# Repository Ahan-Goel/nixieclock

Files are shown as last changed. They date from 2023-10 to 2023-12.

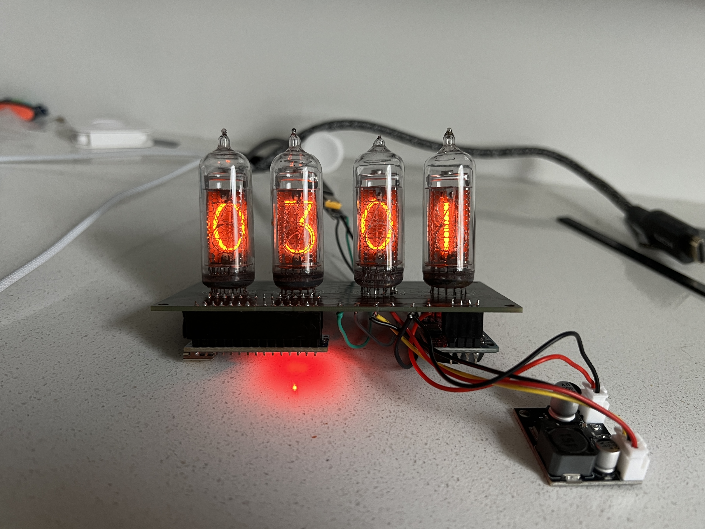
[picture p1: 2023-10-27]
Pictures/Assembled.jpeg

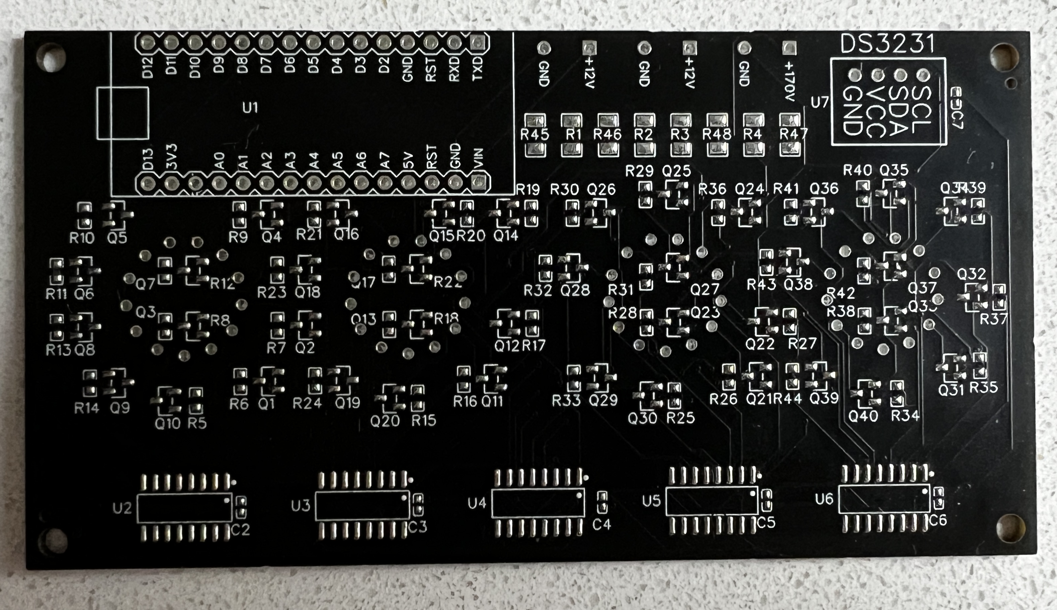
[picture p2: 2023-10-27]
Pictures/PCB Bottom.jpeg

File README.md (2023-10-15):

# nixieclock
Nixie Clock Project I worked on for my UIUC James Scholar Honors Project (ECE 220)

This project involved the research and design of a PCB that utilizes and Arduino to create a retro-themed clock using Nixie tubes.

To build this project it took a lot of research. From deciding how to control the tubes, to the firing and running voltages of the tubes, to parts selection. Using a off the shelf power supply (9v to 170v), along with 40 NPN BJT transistors, 48 resistors, and 5 SN747HC959 shift registers we can create a circuit that when controlled by a microcontroller can display digits on a nixie tube. I spent so many hours researching components, look at datasheets, understanding PCB design and schematic design, while also understanding things about Nixie tubes themselves.

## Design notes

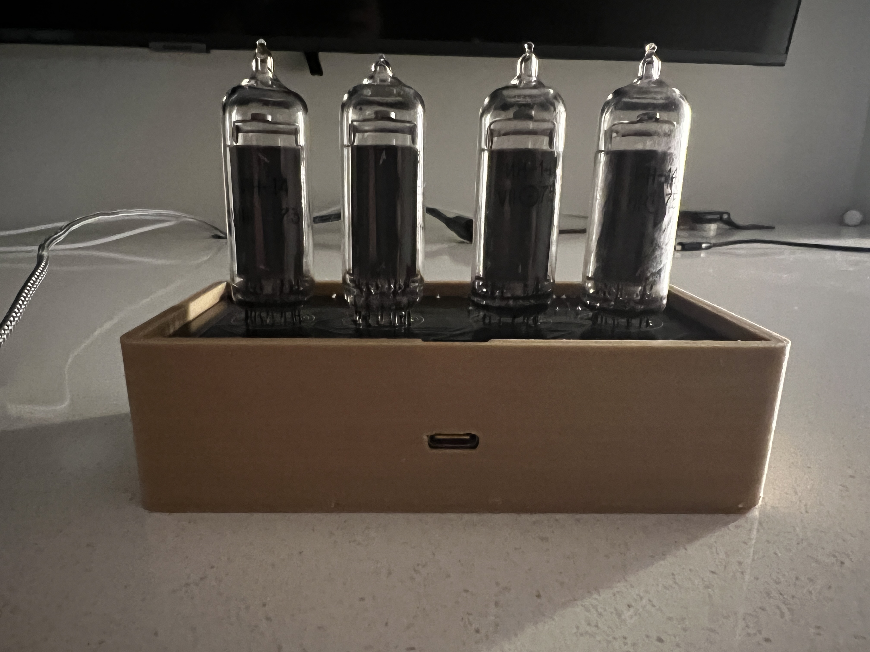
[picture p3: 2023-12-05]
Pictures/FInished Rear.JPG

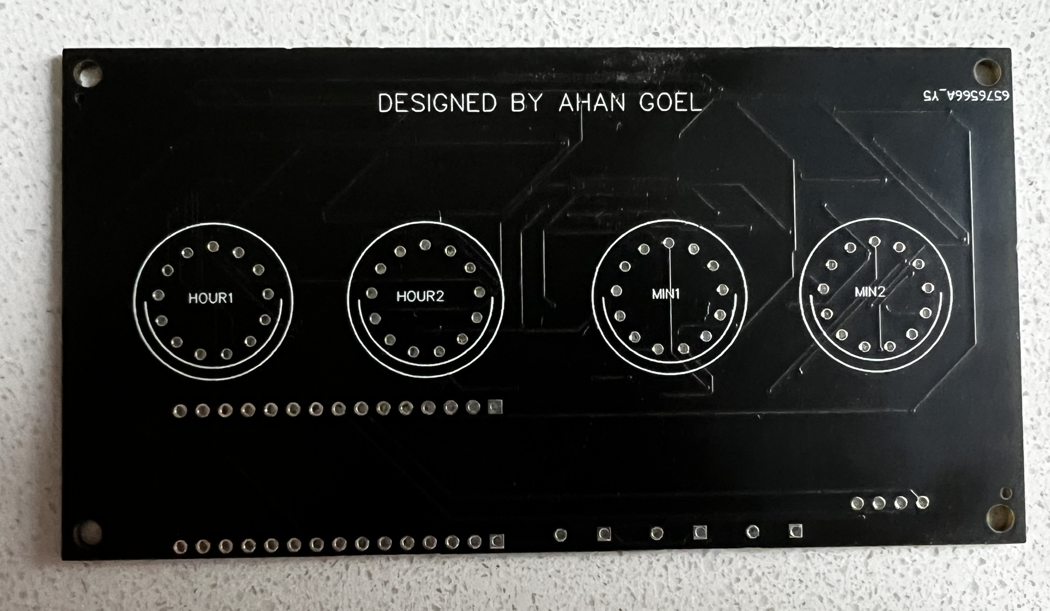
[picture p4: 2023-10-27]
Pictures/PCB Top.jpeg

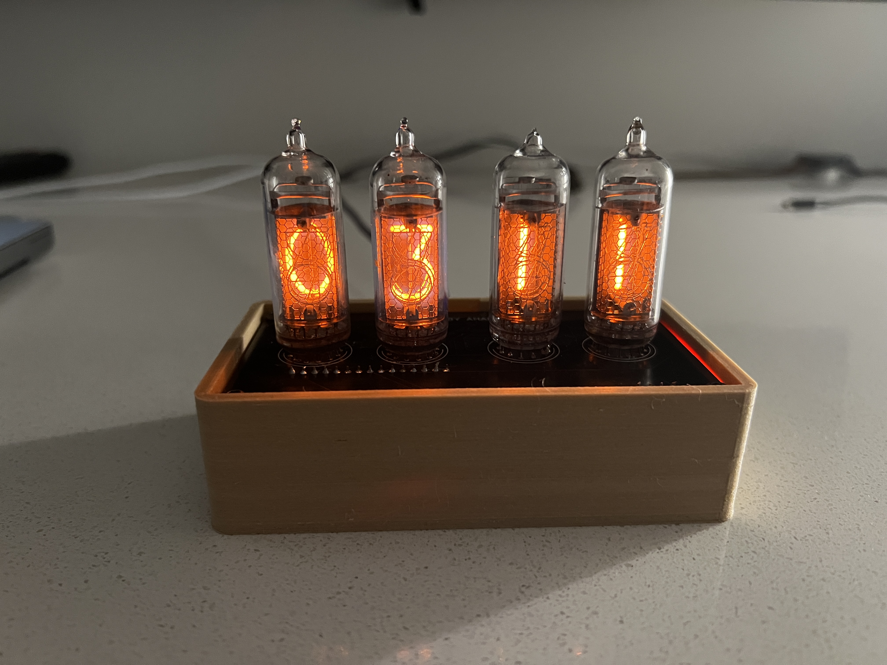
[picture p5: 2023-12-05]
Pictures/Finished Front.JPG

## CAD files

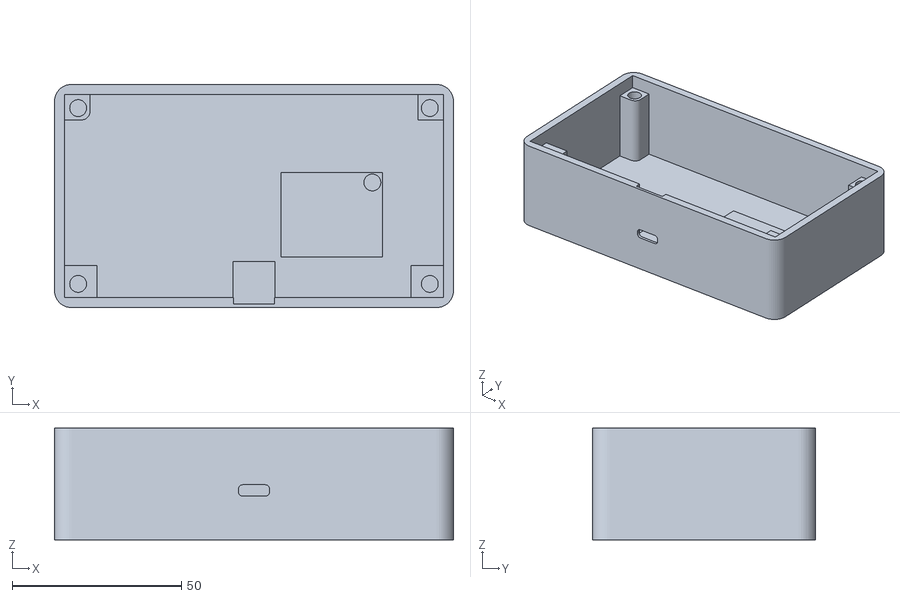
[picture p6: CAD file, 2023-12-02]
CAD Files/Nixie Clock Box.stl
118.0 x 66.0 x 33.0

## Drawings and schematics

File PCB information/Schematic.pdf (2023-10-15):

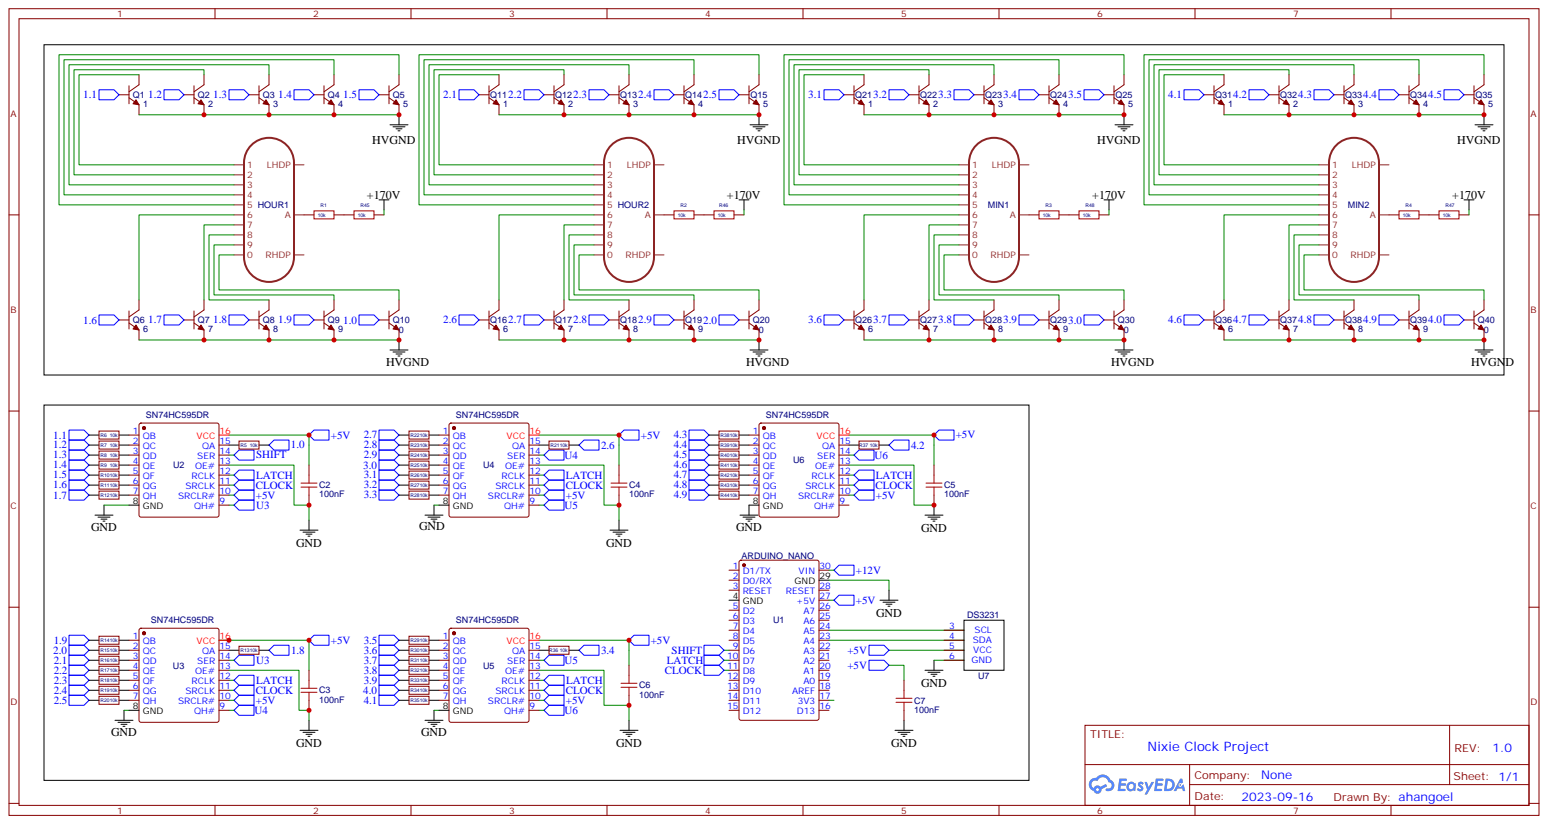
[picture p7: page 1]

SRCLR# 10 SRCLK 11 RCLK 12 OE# 13 SER 14 QA 15 VCC 16

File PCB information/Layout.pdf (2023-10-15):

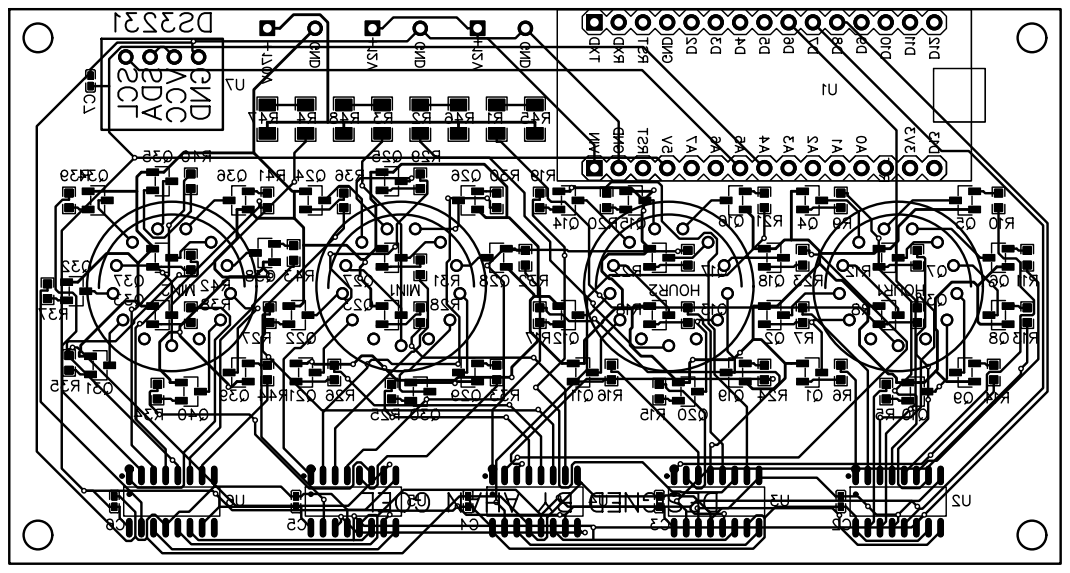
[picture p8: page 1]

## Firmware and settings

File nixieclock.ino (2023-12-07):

#include <Wire.h>
#include <DS3232RTC.h>
#include <Streaming.h> 

DS3232RTC myRTC;

int outputpins[] = {6,8,7}; // Setting pins of arduino
int inputpins[]  = {4,5};
int out_pin_num  = 3;
int in_pin_num   = 2;
int in_loop, out_loop;
bool daylight_savings = false;
bool twelve_hr_time = false;

byte shiftarray[5]; // Shift array

void setup() {
  clear();
  for (in_loop = 0; in_loop < in_pin_num; in_loop++){
    pinMode(inputpins[in_loop], INPUT);
  }
  // Setting input pins
  for (out_loop = 0; out_loop < out_pin_num; out_loop++){
    pinMode(outputpins[out_loop], OUTPUT);
  }
  // Setting output pins

  Serial.begin(9600); // remove "//" to create serial monitor
  myRTC.begin();
  setSyncProvider(myRTC.get);
  clear();
}

void loop() {
  static time_t tLast;
  time_t t;
  tmElements_t tm;
  int hours, minutes, seconds;
  int hour1, hour2, min1, min2;
  // Setting local variables


  if (Serial.available() >= 12) { 
      // Code to set RTC time via Serial Monitor
      // Format: yy,mm,dd,hh,mm,ss

      tm.Year = Serial.parseInt() + 30;
      tm.Month = Serial.parseInt();
      tm.Day = Serial.parseInt();
      tm.Hour = Serial.parseInt();
      tm.Minute = Serial.parseInt();
      tm.Second = Serial.parseInt();

      t = makeTime(tm);
      myRTC.set(t);
      setTime(t);
  }

  hours   = hour();  // Get time and put into local vars (remove -1 for daylight savings)
  minutes = minute();
  seconds = second();

  if (daylight_savings){
    hours -= 1;
  }
  
  if (twelve_hr_time){
    if (hours == 0){ // Convert 24hr to 12hr time
      hours = 12;
    }
    if (hours > 12){ // Convert 24hr to 12hr time
      hours   -= 12;
    }
  }
  hour1   = hours / 10; // Get the individual digits
  hour2   = hours % 10;
  min1    = minutes / 10;
  min2    = minutes % 10;
  //display(9,6,2,4);
  display(hour1, hour2, min1,min2);
  
  //Display the individual digits and check every second
  /*
  Serial.print(hours);
  Serial.print(":");
  Serial.print(minutes);
  Serial.print(":");
  Serial.println(seconds);
  */
  //Debugging code

  delay(1000);
}
int dec2bin(int exp){
  // Turn the time digits into 2^TIME_DIGIT as that is what
  // The shift registers need to show correct value
  int result = 1;
  result <<= exp;
  return result;
}
void prepshift(int value1, int value2, int value3, int value4){
  // Function takes 4 10-bit values and transforms them into
  // 5 8-bit values that can be shifted to registers

  shiftarray[0] = (value1);
  // Bits 0-7 of shiftarray[0] are bits 0-7 of value1
  shiftarray[1] = (value2 << 2) + ((value1 >> 8) & 3);
  // Bits 0-1 of shiftarray[1] are bits 8-9 of value1
  // Bits 2-7 of shiftarray[1] are bits 0-5 of value2
  shiftarray[2] = (value3 << 4) + ((value2 >> 6) & 15);
  // Bits 0-3 of shiftarray[2] are bits 6-9 of value2
  // Bits 4-7 of shiftarray[2] are bits 0-3 of value3
  shiftarray[3] = (value4 << 6) + ((value3 >> 4) & 63);
  // Bits 0-5 of shiftarray[3] are bits 4-9 of value3
  // Bits 6-7 of shiftarray[3] are bits 0-1 of value4
  shiftarray[4] = (value4 >> 2);
  // Bits 0-7 of shiftarray[0] are bits 2-9 of value4
}
void clear(){
  //Clears the clock by setting all transistors to low/out of saturation
  digitalWrite(outputpins[2], LOW);
  for(int i = 0; i < 5; i++){
    shiftOut(outputpins[0], outputpins[1], MSBFIRST, 0);
  }
  digitalWrite(outputpins[2], HIGH);
}
void display(int digit1, int digit2, int digit3, int digit4){
  clear();

  int adjust[10] = {1,0,9,8,7,6,5,4,3,2};
  // Layout Error with imported schematic, not the worst thing we can just change with an array

  int hour1_digit, hour2_digit, min1_digit, min2_digit; // Digits of the clock

  // Figure out the number in binary we have to shift for each digit
  hour1_digit = dec2bin(adjust[digit1]); 
  hour2_digit = dec2bin(adjust[digit2]);
  min1_digit  = dec2bin(adjust[digit3]);
  min2_digit  = dec2bin(adjust[digit4]);
  
  prepshift(hour1_digit, hour2_digit, min1_digit, min2_digit);
  // Prepare the shift by putting the numbers into their arrays

  digitalWrite(outputpins[2],LOW); // Set clock pin low
  shiftOut(outputpins[0],outputpins[1],MSBFIRST,shiftarray[4]);
  shiftOut(outputpins[0],outputpins[1],MSBFIRST,shiftarray[3]);
  shiftOut(outputpins[0],outputpins[1],MSBFIRST,shiftarray[2]);
  shiftOut(outputpins[0],outputpins[1],MSBFIRST,shiftarray[1]);
  shiftOut(outputpins[0],outputpins[1],MSBFIRST,shiftarray[0]);
  digitalWrite(outputpins[2],HIGH); // Set clock pin high
  // Once done shifting the shifting registers push their vals onto the register with a rising edge clock pulse
}

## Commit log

2023-09-09 Added Cad Files
    [Nixie Clock Box Body.stl, Nixie Clock Box Cover.stl, Nixie Clock Box Lid.stl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]
2023-10-14 Functioning code
    [Nixie Clock Box Body.stl, Nixie Clock Box Cover.stl, Nixie Clock Box Lid.stl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]
2023-10-15 Schematic Updated
2023-10-15 Gerber Files Updated
2023-10-15 Added Serial.print statement for time
